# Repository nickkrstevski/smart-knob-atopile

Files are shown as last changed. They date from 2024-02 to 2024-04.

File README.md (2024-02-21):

# smart-knob
Shoutout to Scott Bezek for creating this awesome open source haptic feedback wheel!
https://github.com/scottbez1/smartknob.git

# atopile
>ato install smartknob

This package contains adaptations of the smart knob designs captured in atopile code. atopile will help with jellybean component selection, board layout, versioning, collaboration..

Upon importing the smart knob package into your atopile project, you will find a complete netlist and accompanying layout that can be merged or connected into a larger design. atopile's component selection integrates directly wih the JLC component supplier, generating build outputs that can be directly sent to JLC and show up at your door assembled.

For example, I am creating a chess clock that uses the smart knob as a dial, and adds some leds/capacitive touch sensors to build upon the original design/layout.
https://github.com/nickkrstevski/chess-clock

# Structure
The Smart Knob design consists of 2 PCBAs, a BLDC motor, an LCD, and plenty of mechanical bits holding everything together. This project will contain a Smart Knob module that has 2 build target modules, "SmartKnobBase", and "SmartKnobScreen"

## SmartKnobBase
- ESP32-S3
- USB-C
- BLDC Driver
- Strain Sensor
- Ambient Light Sensor
- Magnetic Quadrature Encoder

## SmartKnobScreen
- Backlight FET/ballast resistor
- LCD Connections

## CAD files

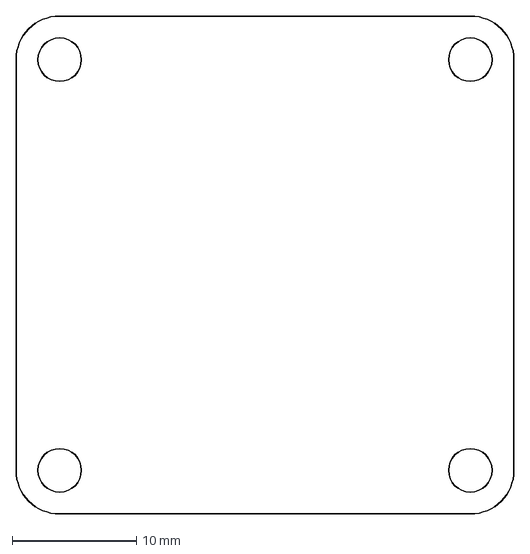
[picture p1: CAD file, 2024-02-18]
mech/template_outline.dxf
40.0 x 40.0 mm

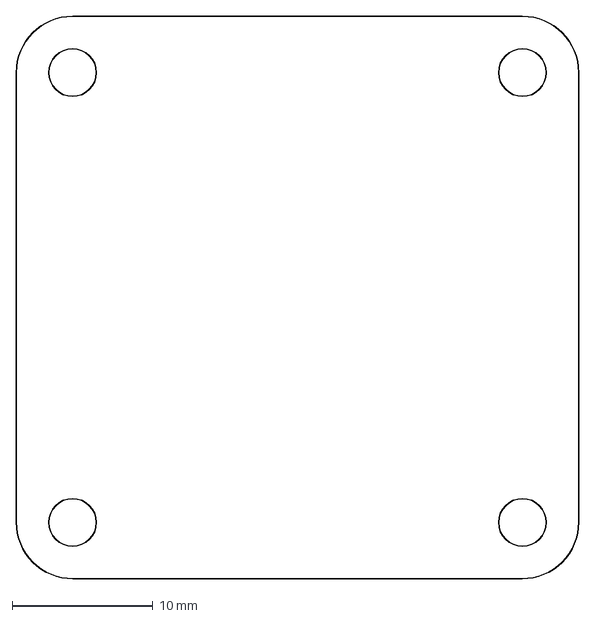
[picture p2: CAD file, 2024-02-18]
mech/template_40x40.dxf
40.0 x 40.0 mm

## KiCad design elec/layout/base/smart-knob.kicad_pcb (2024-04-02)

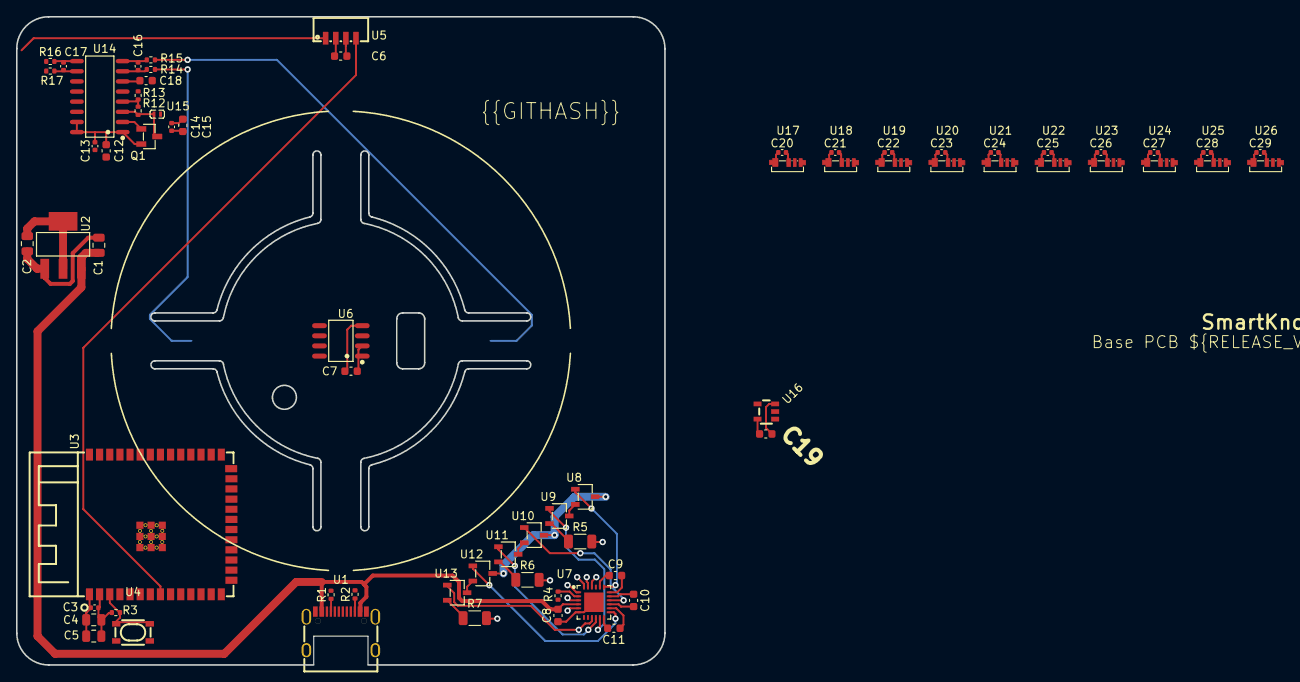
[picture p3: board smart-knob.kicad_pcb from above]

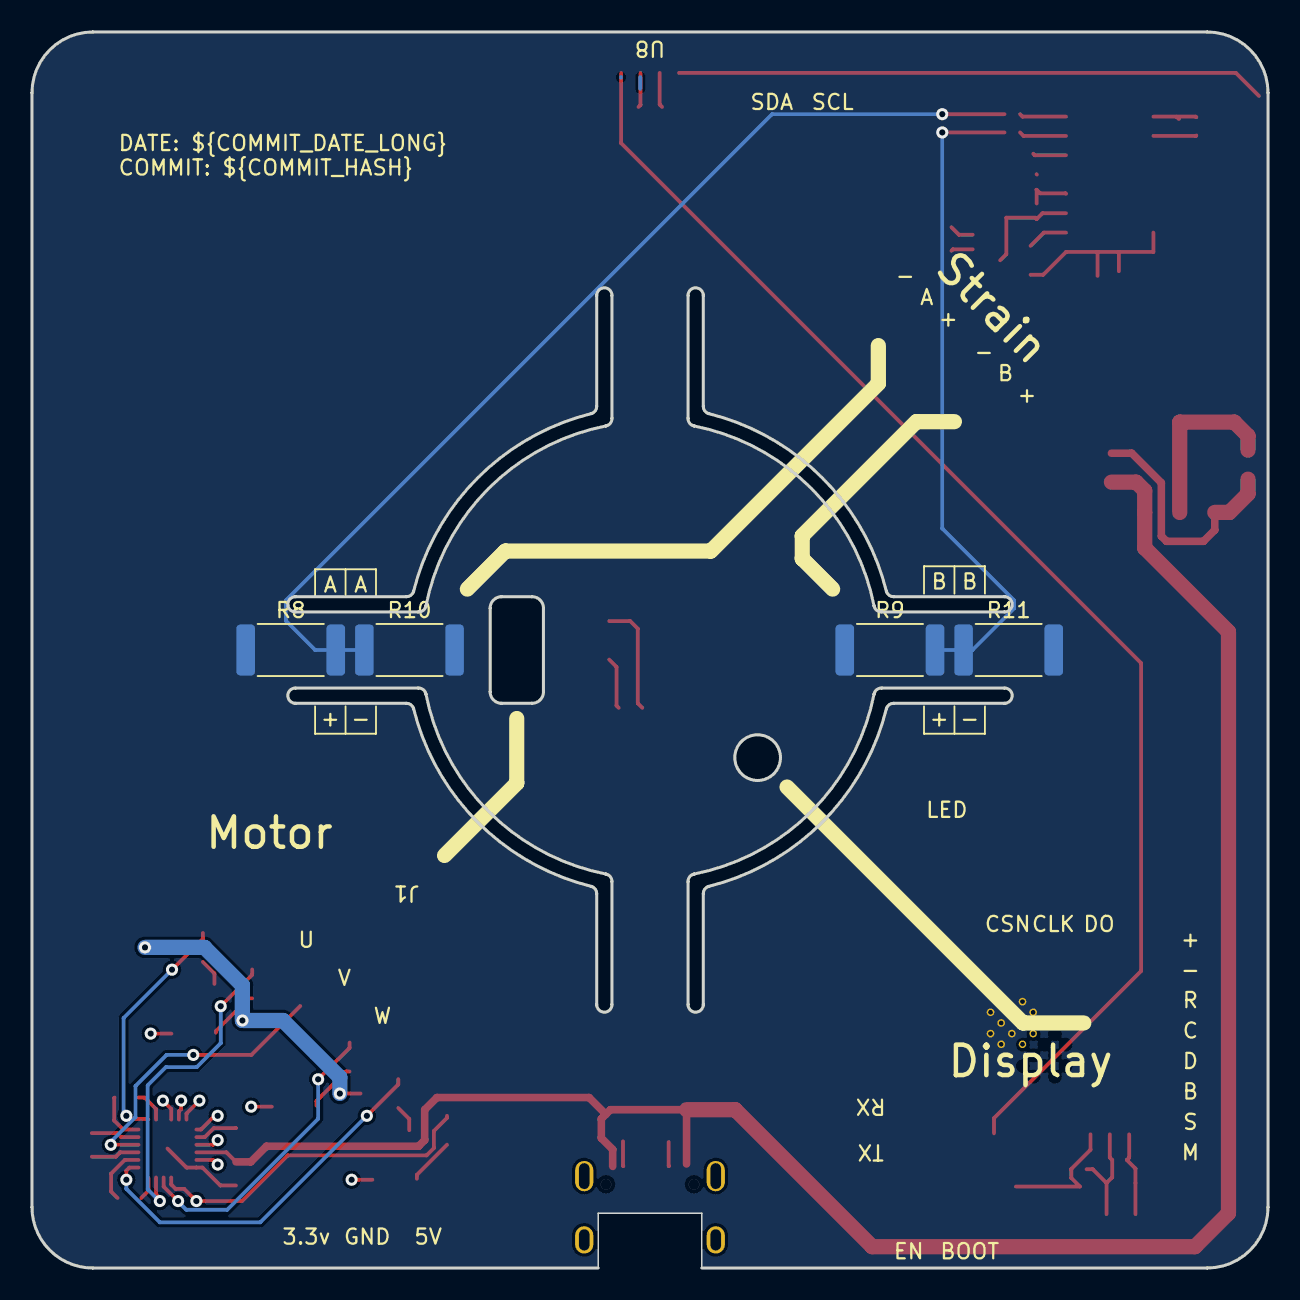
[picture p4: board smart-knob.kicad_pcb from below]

Board: 2 copper layers, 81.2 x 81.2 mm, 74 parts (4 on the bottom side), 64 nets.

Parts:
C1, C2, C4, C5: 25V 10uF X5R ±10% 0805 Multilayer Ceramic Capacit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; C0805
C3, C16, C17: 16V 100nF X7R ±10% 0402 Multilayer Ceramic Capaci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; C0402
C6, C7, C12, C15, C18, C19: 50V 100nF X7R ±10% 0603 Multilayer Ceramic Capaci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; C0603
C8, C9, C10, C11: 50V 1uF X5R ±10% 0603 Multilayer Ceramic Capacito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; C0603
C13, C14: 6.3V 10uF X5R ±20% 0402 Multilayer Ceramic Capaci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; C0402
C20, C21, C22, C23, C24, C25, C26, C27, C28, C29: 25V 1uF X5R ±10% 0402 Multilayer Ceramic Capacito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; C0402
Q1: SOT-23-3_L2.9-W1.3-P1.90-LS2.4-BR
R1, R2: 62.5mW Thick Film Resistors ±100ppm/℃ ±1% 5.1kΩ 0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; R0402
R3, R12: 62.5mW Thick Film Resistors ±100ppm/℃ ±1% 10kΩ 04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; R0402
R4: 62.5mW Thick Film Resistors ±100ppm/℃ ±1% 40.2kΩ 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; R0402
R5, R6, R7: 250mW Thick Film Resistors ±800ppm/℃ ±1% 1Ω 1206 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; R1206
R8, R9, R10, R11: 1W Thick Film Resistors ±100ppm/℃ ±5% 330Ω 2512 C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; R2512
R13: 62.5mW Thick Film Resistors ±100ppm/℃ ±1% 8.2kΩ 0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; R0402
R14, R15, R16, R17: 62.5mW Thick Film Resistors ±1% ±200ppm/℃ 100Ω 04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; R0402
U1: USB-C-SMD_KH-TYPE-C-16P
U2: SOT-223-3_L6.5-W3.4-P2.30-LS7.0-BR
U3: WIRELM-SMD_ESP32-S3-WROOM-1
U4: KEY-SMD_4P-L4.2-W3.2-P2.20-LS4.6
U5: SENSOR-SMD_EML7700-TT
U6: SOP-8_L4.9-W3.9-P1.27-LS6.0-BL
U7: VQFN-24_L4.0-W4.0-P0.50-TL-EP2.5
U8, U9, U10, U11, U12, U13: SOT-23-3_L2.9-W1.6-P1.90-LS2.8-BR
U14: SOP-16_L10.0-W3.9-P1.27-LS6.0-BL
U15: 3.3 +/- 0.99 (30%) microhenry; IND-SMD_L1.2-W0.7
U16: SOT-23-5_L2.9-W1.6-P0.95-LS2.8-BR
U17, U18, U19, U20, U21, U22, U23, U24, U25, U26: LED-SMD_4P-L4.0-W1.4_SK6805SIDE-S
Z5: dummy_keepouts; ViewKeepouts3d

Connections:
base: Q1.1, U14.2
cc1: R1.1, U1.A5
cc2: R2.1, U1.B5
clock: U3.38, U14.11
data: U3.31, U14.12
dm: U1.A7, U1.B7, U3.13
dp: U1.A6, U1.B6, U3.14
en: R3.2, U3.3, U4.1, U4.2
esp32s3.ic-sda: U3.8, U5.4
esp32s3.ic-sda-1: U3.7, U16.2
esp32s3.ic-vcc: U3.28, U7.3
esp32s3.ic-vcc-1: U3.26, U7.1
esp32s3.ic-vcc-2: U3.16, U7.22
esp32s3.ic-vcc-3: U3.11, U7.23
esp32s3.ic-vcc-4: R4.1, U3.10, U7.2
esp32s3.ic-vcc-5: U3.9, U7.24
gnd: R5.2, R6.2, R7.2
hba.nfet_low-source: R5.1, U9.2
hbb.nfet_low-source: R6.1, U11.2
hbc.nfet_low-source: R7.1, U13.2
inna: C16.2, R14.2, U14.7
innb: C17.2, R16.2, U14.9
inpa: C16.1, R15.2, U14.8
inpb: C17.1, R17.2, U14.10
io13: U3.21, U6.7
io14: U3.22, U6.8
io37: U3.30, U6.6
ldo3V3-vcc: C2.1, C3.1, C4.1, C5.1, C12.1, C13.1, Q1.2, R3.1, U2.2, U2.4, U3.2, U14.1, U14.15, U14.16
led1-vcc-1: U17.3, U18.4
led2-vcc: U18.3, U19.4
led3-vcc: U19.3, U20.4
led4-vcc: U20.3, U21.4
led5-vcc: U21.3, U22.4
led6-vcc: U22.3, U23.4
led7-vcc: U23.3, U24.4
led8-vcc: U24.3, U25.4
led9-vcc: U25.3, U26.4
light_sensor.ic-gnd: C6.2, U5.3
light_sensor.ic-vcc: C6.1, U5.2
n: R9.2, R11.1, R14.1
p: R8.2, R10.1, R15.1
phase_a: U8.2, U9.3
phase_b: U10.2, U11.3
phase_c: U12.2, U13.3
power_stage-vcc-1: U7.11, U9.1
power_stage-vcc-2: U7.10, U11.1
power_stage-vcc-3: U7.9, U13.1
power_stage-vcc-4: U7.19, U8.1
power_stage-vcc-5: U7.16, U10.1
power_stage-vcc-6: U7.13, U12.1
power_stage-vcc-7: C9.2, U7.18
power_stage-vcc-8: C10.2, U7.15
power_stage-vcc-9: C11.2, U7.12
power_stage.ic-vcc: C9.1, U7.20
power_stage.ic-vcc-1: C10.1, U7.17
power_stage.ic-vcc-2: C11.1, U7.14
scl: U3.12, U5.1
strain_adc.ic-vcc: Q1.3, R12.1, U14.3, U15.1
usbc-gnd: C1.2, C2.2, C3.2, C4.2, C5.2, C7.2, C8.2, C12.2, C13.2, C14.2, C15.2, C18.2, C19.2, C20.2, C21.2, C22.2, C23.2, C24.2, C25.2, C26.2, C27.2, C28.2, C29.2, R1.2, R2.2, R4.2, R10.2, R11.2, R13.2, U1.1, U1.2, U1.3, U1.4, U1.A1, U1.A12, U1.B1, U1.B12, U2.1, U3.1, U3.40, U3.41, U4.3, U4.4, U6.4, U7.6, U7.25, U14.5, U14.14, U16.3, U17.2, U18.2, U19.2, U20.2, U21.2, U22.2, U23.2, U24.2, U25.2, U26.2
usbc-vcc: C1.1, C7.1, C8.1, C19.1, C20.1, C21.1, C22.1, C23.1, C24.1, C25.1, C26.1, C27.1, C28.1, C29.1, U1.A4, U1.A9, U1.B4, U1.B9, U2.3, U6.1, U6.2, U7.4, U16.5, U17.1, U18.1, U19.1, U20.1, U21.1, U22.1, U23.1, U24.1, U25.1, U26.1
vbg: C18.1, U14.6
vcc: U8.3, U10.3, U12.3
vcc-1: C14.1, C15.1, R8.1, R9.1, U15.2
vfb: R12.2, R13.1, U14.4

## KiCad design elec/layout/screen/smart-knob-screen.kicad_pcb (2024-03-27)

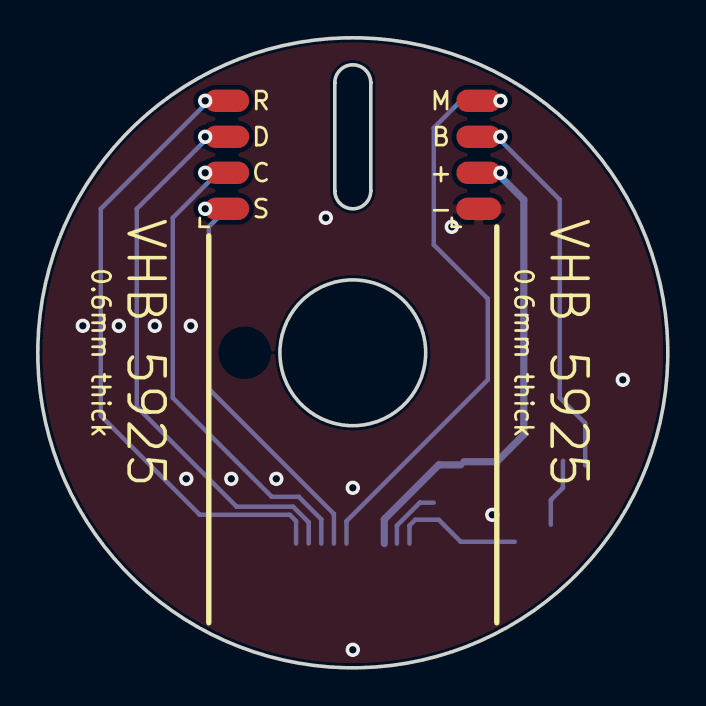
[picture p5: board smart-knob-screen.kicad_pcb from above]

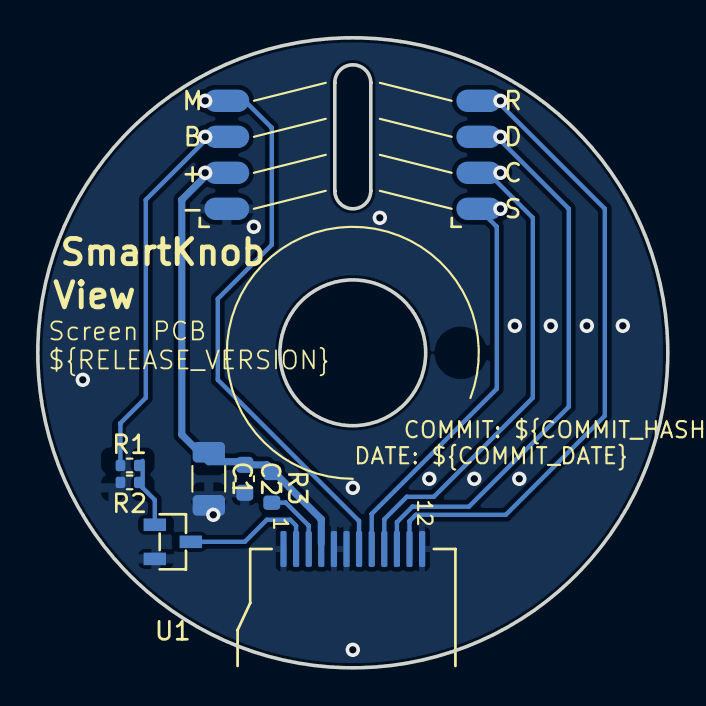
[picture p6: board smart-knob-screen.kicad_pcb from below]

Board: 2 copper layers, 35.0 x 35.0 mm, 11 parts (9 on the bottom side), 3 nets.

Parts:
C1: 25V 22uF X5R ±10% 1206 Multilayer Ceramic Capacit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; C1206
C2: 50V 100nF X7R ±10% 0603 Multilayer Ceramic Capaci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; C0603
J1, J3, J4, J5: Conn_01x04; SolderPads_2mm_4
J2: GC9A01; GC9A01Round1.28
R1: 62.5mW Thick Film Resistors ±100ppm/℃ ±1% 10kΩ 04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; R0402
R2: 62.5mW Thick Film Resistors ±100ppm/℃ ±1% 1MΩ 040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; R0402
R3: 100mW Thick Film Resistors ±100ppm/℃ ±1% 22Ω 0603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; R0603
U1: SOT-23-3_L2.9-W1.3-P1.90-LS2.4-BR

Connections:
gate: R1.2, R2.1, U1.1
gnd: C1.2, C2.2, R2.2, U1.2
vcc: C1.1, C2.1, R3.1

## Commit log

2024-02-18 Configure project
    [smart-knob.kicad_pcb, smart-knob.kicad_sch]
2024-02-21 base and screen implemented, need 2 conn bldc driver
2024-02-21 connected 10 leds
2024-02-23 just need motor driver
2024-02-28 building, added power stage and half bridges
2024-03-27 screen layout complete
    [smart-knob-screen.kicad_pcb, smart-knob-screen.kicad_sch, smart-knob.kicad_pcb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]
2024-03-28 base layout 40% complete
    [smart-knob.kicad_pcb]
2024-04-02 chugging thru layout
    [smart-knob.kicad_pcb]

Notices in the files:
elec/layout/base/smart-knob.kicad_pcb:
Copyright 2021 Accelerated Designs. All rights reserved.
